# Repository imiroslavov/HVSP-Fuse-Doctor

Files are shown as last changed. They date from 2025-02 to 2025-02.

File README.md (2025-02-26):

# HVSP Fuse Doctor

The story began a long time ago. As of the moment that I am writing this README.md almost 21 years passed since then. 
I was really passionate to learn how to design and make my own hardware so I started learning how to make my own schematics, PCBs and how to program microcontrollers. 
Unfortunately I didn't knew how to properly program fuses and what was the difference between a crystal and clock oscillator so I ended up with a pile of "dead" microcontrollers. 
Back in these days I had a self made High-voltage programmer (The almighty "ByteBlaster+". I will post schematics and board design on another repository) but nowadays I have no place to plug it in since LPT ports are long time out of use in modern computing. 
I was developing a Low-ohm continuity tester with ATtiny2313 and accidentally bricked the MCU in my personal "old-school style" way (I've pulled my beard at least 1cm longer) and guess what... 
It was the last one in the box that was alive. So the journey began. 
I've ended up finding a lot of schematics and information, but most of it was related to using Arduino which for me was just a big "Ehh!". 
I found a few blog posts which helped me to design the device to be dependent on the power supply only (credits on the end of the page).

## Pinout

| PIN  | AVR | HVSP |
| --- | --- | --- |
| 1 | PC5 | **12V / RST** |
| 2 | PC0 | **SDI** |
| 3 | PC1 | **SII** |
| 4 | PC2 | **SDO** |
| 5 | PC3 | **SCI** |
| 6 | PC4 | **5V / VCC** |
| 7 | GND | **GND** |

## Schematics
This is the base schematic. Version 2 contains additional header connected to PD1 and GND which is used for RS232 communication and can be omitted. Thus the connector it's not shown here because it is optional.

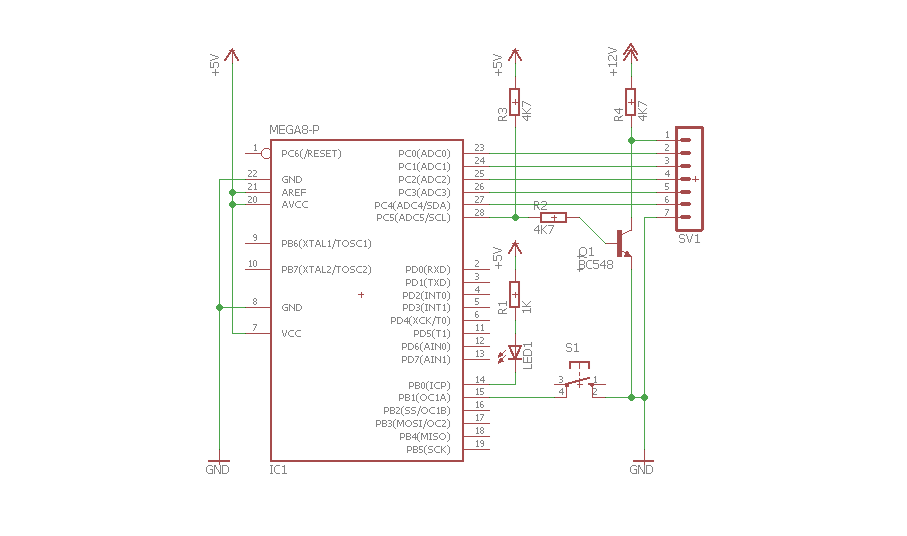
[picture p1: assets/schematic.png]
Schematic


## Board prototype v1 (dual power supply 5V/12V)
| Bottom layer | Top view |
|:---:|:---:|
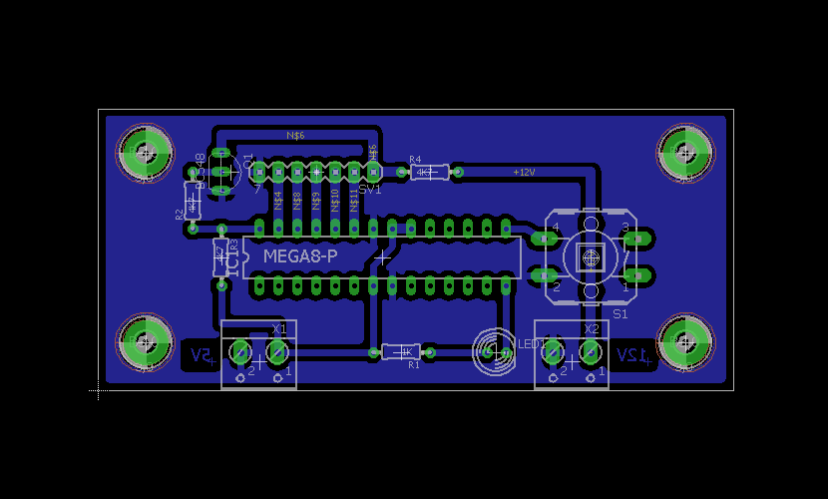
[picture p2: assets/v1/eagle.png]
Eagle
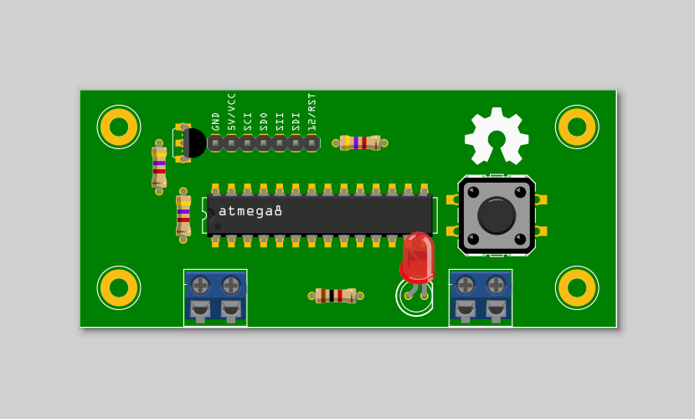
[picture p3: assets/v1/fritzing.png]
Fritzing
|  |  |

Please note that the main.sch has additional sheet containing the mounting pads and connectors not shown in the schematics diagram above. They are there, but feel free to change them to make your own design (I've used one of those power supplies for external SATA disk drive readers that provide 5 and 12 volts simultaneously (DIN6)). 

## Notes
If the system still does not answer for a simple ISP programmer, that means the MCU has damaged hardware SPI, other damage or bad EEPROM.

Thanks to Peter Fleury at http://www.peterfleury.epizy.com/ for the original schematics and code. I've changed it of course but it is based on his work.

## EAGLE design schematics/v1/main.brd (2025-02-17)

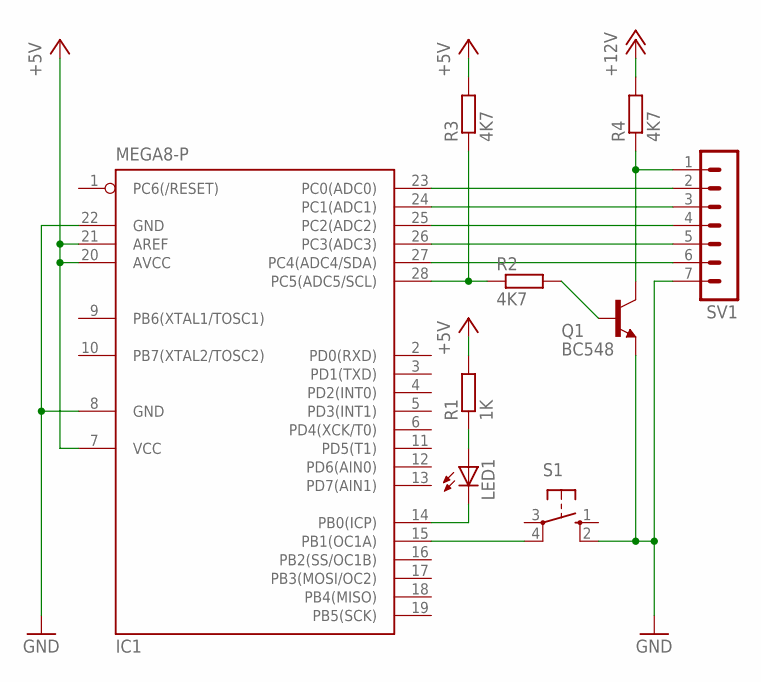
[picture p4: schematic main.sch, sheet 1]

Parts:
IC1: MEGA8-P; DIL28-3
LED1: LED5MM
Q1: BC548; TO92-EBC
R1: 1K; 0204/7
R2, R3, R4: 4K7; 0204/7
S1: 40-XX; B3F-40XX
SV1: MA07-1

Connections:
+5V: IC1.7 (VCC), IC1.20 (AVCC), IC1.21 (AREF), R1.2, R3.2; also elsewhere on the board
+12V: R4.2; also elsewhere on the board
GND: IC1.8 (GND), IC1.22 (GND), Q1.E, S1.2 (S1), SV1.7; also elsewhere on the board
unnamed: IC1.15 (PB1(OC1A)), S1.4 (P1)
unnamed: IC1.14 (PB0(ICP)), LED1.K (C)
unnamed: LED1.A, R1.1
unnamed: IC1.27 (PC4(ADC4/SDA)), SV1.6
unnamed: Q1.B, R2.2
unnamed: Q1.C, R4.1, SV1.1
unnamed: IC1.28 (PC5(ADC5/SCL)), R2.1, R3.1
unnamed: IC1.26 (PC3(ADC3)), SV1.5
unnamed: IC1.25 (PC2(ADC2)), SV1.4
unnamed: IC1.24 (PC1(ADC1)), SV1.3
unnamed: IC1.23 (PC0(ADC0)), SV1.2

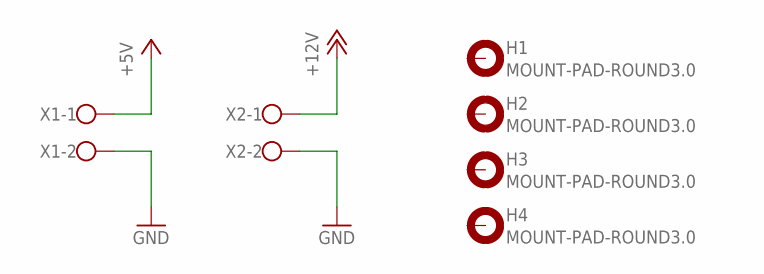
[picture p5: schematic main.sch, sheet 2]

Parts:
H1, H2, H3, H4: MOUNT-PAD-ROUND3.0; 3,0-PAD
X1, X2: W237-102

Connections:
+5V: X1.1; also elsewhere on the board
+12V: X2.1; also elsewhere on the board
GND: X1.2, X2.2; also elsewhere on the board

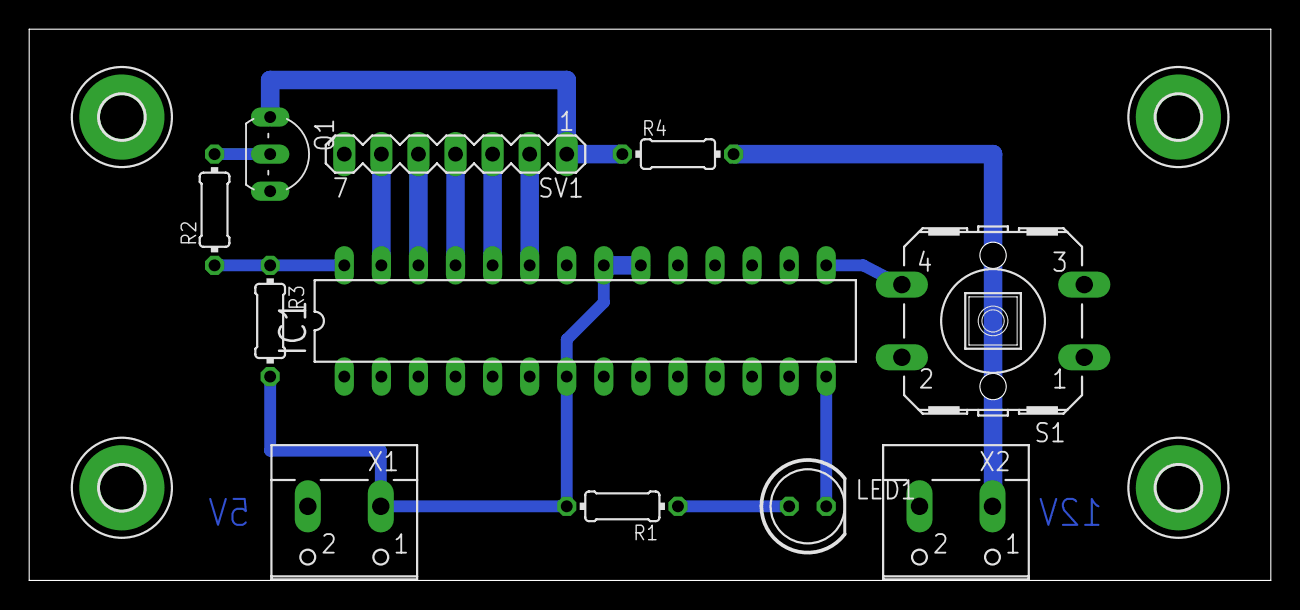
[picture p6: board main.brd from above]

Board: 2 copper layers, 85.1 x 37.8 mm, 15 parts (0 on the bottom side), 14 nets.

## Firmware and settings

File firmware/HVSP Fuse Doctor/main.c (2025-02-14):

/******************************************************************************
Title:      HVSP Fuse Doctor
Hardware:   ATmega8 or any AVR with at least 8 IO pins
License:    GNU General Public License
Author:     Iliya Miroslavov Iliev (i.miroslavov@gmail.com)

DESCRIPTION:
Restore the fuse bits of a any AVR to factory defaults
using High-voltage Serial Programming (HVSP).

*******************************************************************************/
#include <inttypes.h>
#include <stdbool.h>
#include <avr/io.h>
#include <avr/sleep.h>
#include <util/delay.h>
#include <avr/pgmspace.h>
#include "main.h"
#include "mcus.h"

static inline void clockit(void)
{
    HVSP_SCI_OUT |= (1 << HVSP_SCI);

    // The minimum period for the Serial Clock Input (SCI) during High-voltage Serial Programming is 220ns. Waiting 1us just in case.
    _delay_us(1);

    HVSP_SCI_OUT &= ~(1 << HVSP_SCI);
}

/*
* Send instruction and data byte to the target and read one byte from it
*/
static uint8_t transferByte(uint8_t data, uint8_t instruction)
{
    uint8_t byteRead = 0;

    // Set first bit to zero
    ZEROINPUTS();
    clockit();

    for (uint8_t i = 0; i < 8; i++)
    {
        // Read one bit form SDO
        byteRead <<= 1; // Clear LSB by shifting 1 bit
        if (0 != (HVSP_SDO_IN & (1 << HVSP_SDO)))
        {
            byteRead |= 1;
        }

        // Output next data bit on SDI
        if (data & 0x80)
        {
            HVSP_SDI_OUT |= (1 << HVSP_SDI);
        }
        else
        {
            HVSP_SDI_OUT &= ~(1 << HVSP_SDI);
        }

        // Output next instruction bit on SII
        if (instruction & 0x80)
        {
            HVSP_SII_OUT |= (1 << HVSP_SII);
        }
        else
        {
            HVSP_SII_OUT &= ~(1 << HVSP_SII);
        }

        clockit();

        // Prepare for processing next bit
        data <<= 1;
        instruction <<= 1;
    }

    // Set last two bits to zero
    ZEROINPUTS();
    clockit();
    clockit();

    return byteRead;
}

static void pollSDO(void)
{
    // Wait until SDO goes high
    while (0 == (HVSP_SDO_IN & _BV(HVSP_SDO)));
}

static uint8_t getSignature(uint8_t code)
{
    transferByte(0x08, 0x4C);
    transferByte(code, 0x0C);
    transferByte(0x00, 0x68);

    return transferByte(0x00, 0x6C);
}

static void writeFuseBits(uint8_t code, uint8_t A, uint8_t B)
{
    transferByte(0x40, 0x4C);
    transferByte(code, 0x2C);
    transferByte(0x00, A);
    transferByte(0x00, B);

    pollSDO();

    transferByte(0x00, 0x4C);

    pollSDO();
}

#define WRITE_FUSE_BIT_LOW(code)  writeFuseBits(code, 0x64, 0x6C)
#define WRITE_FUSE_BIT_HIGH(code) writeFuseBits(code, 0x74, 0x7C)
#define WRITE_FUSE_BIT_EXT(code)  writeFuseBits(code, 0x66, 0x6E)

static uint8_t readFuseBits(uint8_t A, uint8_t B)
{
    transferByte(0x04, 0x4C);
    transferByte(0x00, A);

    return transferByte(0x00, B);
}

#define READ_FUSE_BIT_LOW()  readFuseBits(0x68, 0x6C)
#define READ_FUSE_BIT_HIGH() readFuseBits(0x7A, 0x7E)
#define READ_FUSE_BIT_EXT()  readFuseBits(0x6A, 0x6E)

int main(void)
{
    /*
    The following algorithm puts the device in High-voltage Serial Programming mode:
    (see Atmel data sheet for "High Voltage Serial Programming")

    1. Set Prog_enable pins (SDI, SII, SDO, SCI)  0 , RESET pin and VCC to 0V.
    2. Apply 5V between VCC and GND. Ensure that VCC reaches at least 1.8V within the next 20 microseconds.
    3. Wait 20 - 60 us, and apply 11.5 - 12.5V to RESET.
    4. Keep the Prog_enable pins unchanged for at least 10 us after the High-voltage has been
       applied to ensure the Prog_enable Signature has been latched.
    5. Release the Prog_enable[2] (SDO pin) to avoid drive contention on the Prog_enable[2]/SDO pin.
    6. Wait at least 300 us before giving any serial instructions on SDI/SII.
    7. Exit Programming mode by power the device down or by bringing RESET pin to 0V.
    */

    // Set LED pin as output and initially off
    LED_DDR  = (1 << LED_PIN);
    LED_OUT |= (1 << LED_PIN);

    // Turn on internal pull-up for push button
    SWITCH_DDR &= ~(1 << SWITCH_PIN);
    SWITCH_OUT |= (1 << SWITCH_PIN);

    while (1)
    {
        bool success = false;

        // Set the LED initially off
        LED_OUT |= (1 << LED_PIN);

        // Start when push button is pushed
        if (0 == (SWITCH_IN & (1 << SWITCH_PIN)))
        {
            // 1. Set all pins as output
            HVSP_SCI_DDR  |= (1 << HVSP_SCI);
            HVSP_SII_DDR  |= (1 << HVSP_SII);
            HVSP_SDI_DDR  |= (1 << HVSP_SDI);
            HVSP_SDO_DDR  |= (1 << HVSP_SDO);
            HVSP_RST_DDR  |= (1 << HVSP_RST);
            HVSP_VCC_DDR  |= (1 << HVSP_VCC);

            // Set pins to 0, RST to 1 because of the inverting NPN transistor
            HVSP_SCI_OUT &= ~(1 << HVSP_SCI);
            HVSP_SII_OUT &= ~(1 << HVSP_SII);
            HVSP_SDI_OUT &= ~(1 << HVSP_SDI);
            HVSP_SDO_OUT &= ~(1 << HVSP_SDO);
            HVSP_RST_OUT |=  (1 << HVSP_RST);
            HVSP_VCC_OUT &= ~(1 << HVSP_VCC);

            // 2. Apply VCC 5V to target
            HVSP_VCC_OUT |= (1 << HVSP_VCC);

            // 3. Wait 20-60us before applying 12V to RESET
            _delay_us(60);
            HVSP_RST_OUT &= ~(1 << HVSP_RST);

            // 4. Keep the Prog_enable pins unchanged for at least 10us after the high-voltage has been applied
            _delay_us(20);

            // 5. Switch Prog_enable[2] (SDO pin) to input
            HVSP_SDO_DDR  &= ~(1 << HVSP_SDO);

            // 6. Wait >=300us before sending any data on SDI/SII
            _delay_us(300);

            for (uint8_t device = 0; 0 != pgm_read_byte(&targetMCU[device].signature[0]); device++)
            {
                if (getSignature(0) == pgm_read_byte(&targetMCU[device].signature[0]) &&
                    getSignature(1) == pgm_read_byte(&targetMCU[device].signature[1]) &&
                    getSignature(2) == pgm_read_byte(&targetMCU[device].signature[2]))
                {
                    // Get default fuse bits for selected target
                    uint8_t fuseLowBits      = pgm_read_byte(&targetMCU[device].fuseLowBits);
                    uint8_t fuseHighBits     = pgm_read_byte(&targetMCU[device].fuseHighBits);
                    uint8_t fuseExtendedBits = pgm_read_byte(&targetMCU[device].fuseExtendedBits);

                    // Write default fuse bits
                    WRITE_FUSE_BIT_LOW(fuseLowBits);
                    WRITE_FUSE_BIT_HIGH(fuseHighBits);

                    if (0 != fuseExtendedBits)
                    {
                        WRITE_FUSE_BIT_EXT(fuseExtendedBits);
                    }

                    // Verify results
                    if ((fuseLowBits == READ_FUSE_BIT_LOW()) &&
                        (fuseHighBits == READ_FUSE_BIT_HIGH()) &&
                        ((0 ==fuseExtendedBits) || (fuseExtendedBits == READ_FUSE_BIT_EXT())))
                    {
                         success = true;
                    }

                    break;
                }
            }

            // 7. Exit Programming mode by setting all pins to 0 and then power off the device
            HVSP_SCI_OUT &= ~(1 << HVSP_SCI);
            HVSP_SII_OUT &= ~(1 << HVSP_SII);
            HVSP_SDI_OUT &= ~(1 << HVSP_SDI);
            HVSP_RST_OUT |=  (1 << HVSP_RST);
            _delay_us(10);
            HVSP_VCC_OUT &= ~(1 << HVSP_VCC);

            // Turn on the LED for 4 sec if the fuse restore was successful or flash the LED on error
            for (int i = 0; i < 16; i++)
            {
                if (success)
                {
                    LED_OUT &= ~(1 << LED_PIN);
                }
                else
                {
                    LED_OUT ^= (1 << LED_PIN);
                }

                _delay_ms(250);
            }
        }
    }
}

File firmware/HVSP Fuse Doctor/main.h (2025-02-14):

#ifndef MAIN_H_
#define MAIN_H_

/*
* Port/Pin defines, adapt to your selected AVR and circuit
*/
#define HVSP_SDI_OUT PORTC
#define HVSP_SDI_DDR DDRC
#define HVSP_SDI     PC0 // Serial Data Input on target

#define HVSP_SII_OUT PORTC
#define HVSP_SII_DDR DDRC
#define HVSP_SII     PC1 // Serial Instruction Input on target

#define HVSP_SDO_OUT PORTC
#define HVSP_SDO_IN  PINC
#define HVSP_SDO_DDR DDRC
#define HVSP_SDO     PC2 // Serial Data Output on target

#define HVSP_SCI_OUT PORTC
#define HVSP_SCI_DDR DDRC
#define HVSP_SCI     PC3 // Serial Clock Input on target

#define HVSP_VCC_OUT PORTC
#define HVSP_VCC_DDR DDRC
#define HVSP_VCC     PC4 // VCC to target

#define HVSP_RST_OUT PORTC
#define HVSP_RST_DDR DDRC
#define HVSP_RST     PC5 // +12V to reset pin on target (inverted through NPN transistor)

#define LED_OUT      PORTB
#define LED_DDR      DDRB
#define LED_PIN      PB0 // LED to show result

#define SWITCH_OUT   PORTB
#define SWITCH_DDR   DDRB
#define SWITCH_IN    PINB
#define SWITCH_PIN   PB1 // Push button to start fuse restore

#define ZEROINPUTS() HVSP_SDI_OUT &= ~(1 << HVSP_SDI); \
                     HVSP_SII_OUT &= ~(1 << HVSP_SII)

/*
* Structure to hold signature and default fuse bits of target to be programmed
* See MCU data sheet or avr-libc include files iotnxx.h for the values of LFUSE_DEFAULT, HFUSE_DEFAULT, EFUSE_DEFAULT
* or use Atmel AVR Fuse Calculator: http://www.engbedded.com/fusecalc/
*/
typedef struct TARGET_MCU_INFO_struct {
    uint8_t signature[3];
    uint8_t fuseLowBits;
    uint8_t fuseHighBits;
    uint8_t fuseExtendedBits;
} TARGET_MCU_INFO_t;

#endif /* MAIN_H_ */

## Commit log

2025-02-14 Firmware prototype (WIP)
2025-02-17 Adding schematics v1
    [main.brd, main.sch]
2025-02-17 Adding schematics, board and credits
2025-02-17 Update README.md
    Prototype v2 will have a single power source and voltage regulators for 5V and 12 V
2025-02-18 Upload fritzing like PCB
2025-02-18 Adding fritzing style board to the readme
2025-02-18 Working on version 2
    [main.brd, main.sch]
2025-02-26 Adding info about schematics of v2
